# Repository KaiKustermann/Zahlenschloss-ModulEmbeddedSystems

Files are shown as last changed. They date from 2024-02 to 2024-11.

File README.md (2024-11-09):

# Documentation Project Zahlenschloss

## 1. Contributors

- Kai Kustermann (kk147)
- Hannes Frey (hf018)

## 2. Project Description

The project implements a safe using an ATmega328P as microcontroller, a 4x4 matrix keypad to capture user input and an LCD display as output to display important information about the state of the system. Two LEDs are used to indicate if the safe is open or closed. A DC locking bolt acts as mechanic mechanism for closing and opening the lock, which operates using a mosfet. Optionally a buzzer can be added to give auditory feedback to the user.
The project is written in C using AVR-GCC as compiler without any additional libraries as external dependencies.

## 3. Hardware Setup

Hardware needed:
 - Arduino Uno or clone
 - 2 colored LEDs
 - LED resistors
 - 4x4 matrix pin pad
 - 16x2 LCD Display with IO expander
 - Mosfet module
 - 5V bolt pin lock

Depending on how you want to design the safe, you may choose to use our CAD files to directly print oder edit the design to your liking. Alternatively a box made of wood can be crafted based on the original design.

### 3.1 Circuit Diagram

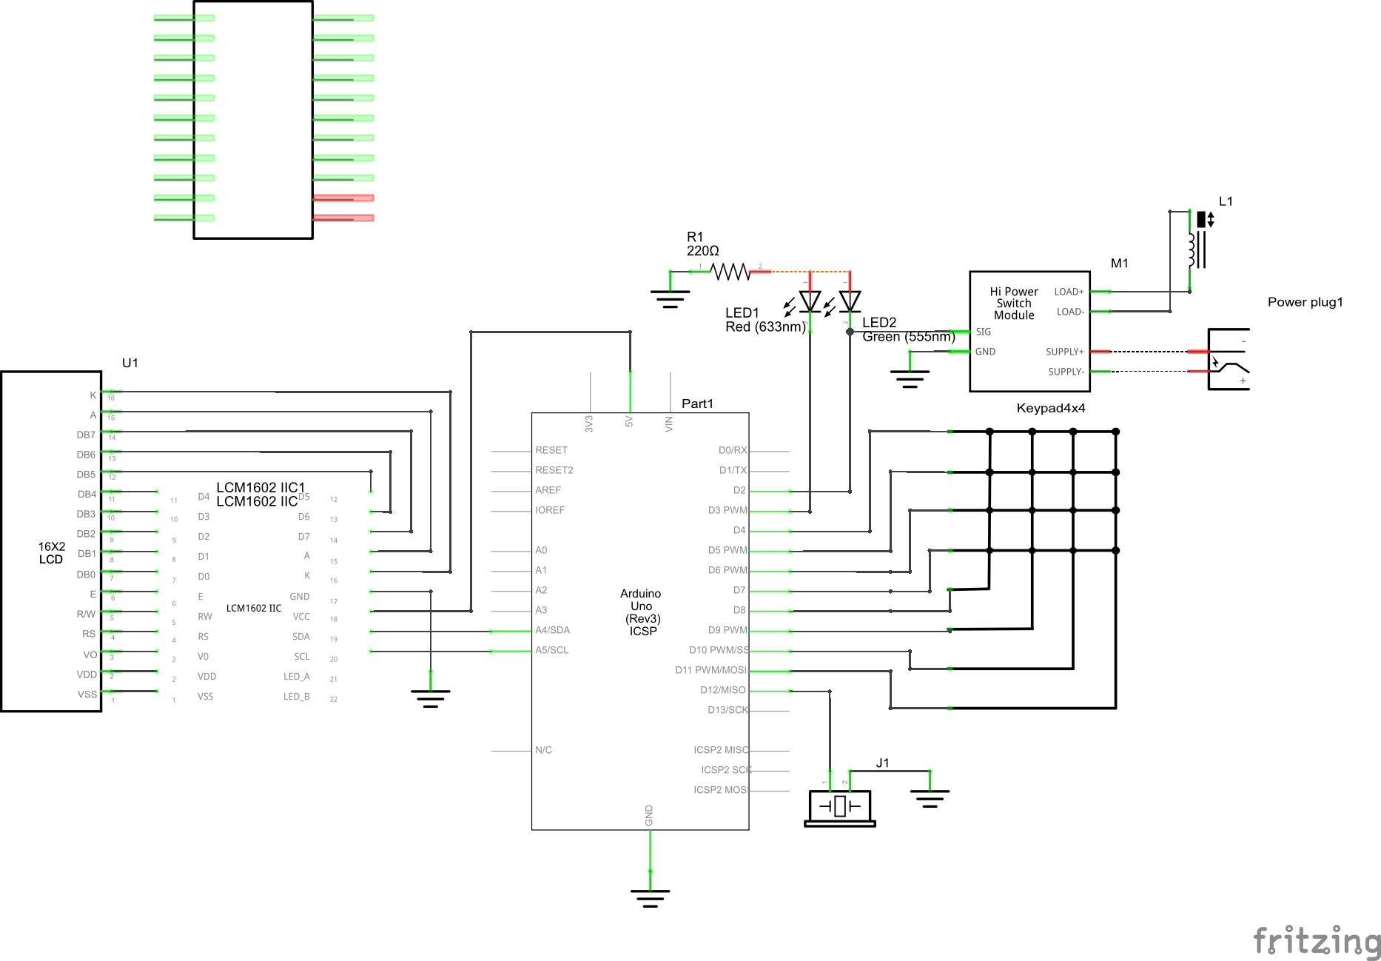
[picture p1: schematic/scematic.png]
Electric schematic


### 3.2 Breadboard Diagram

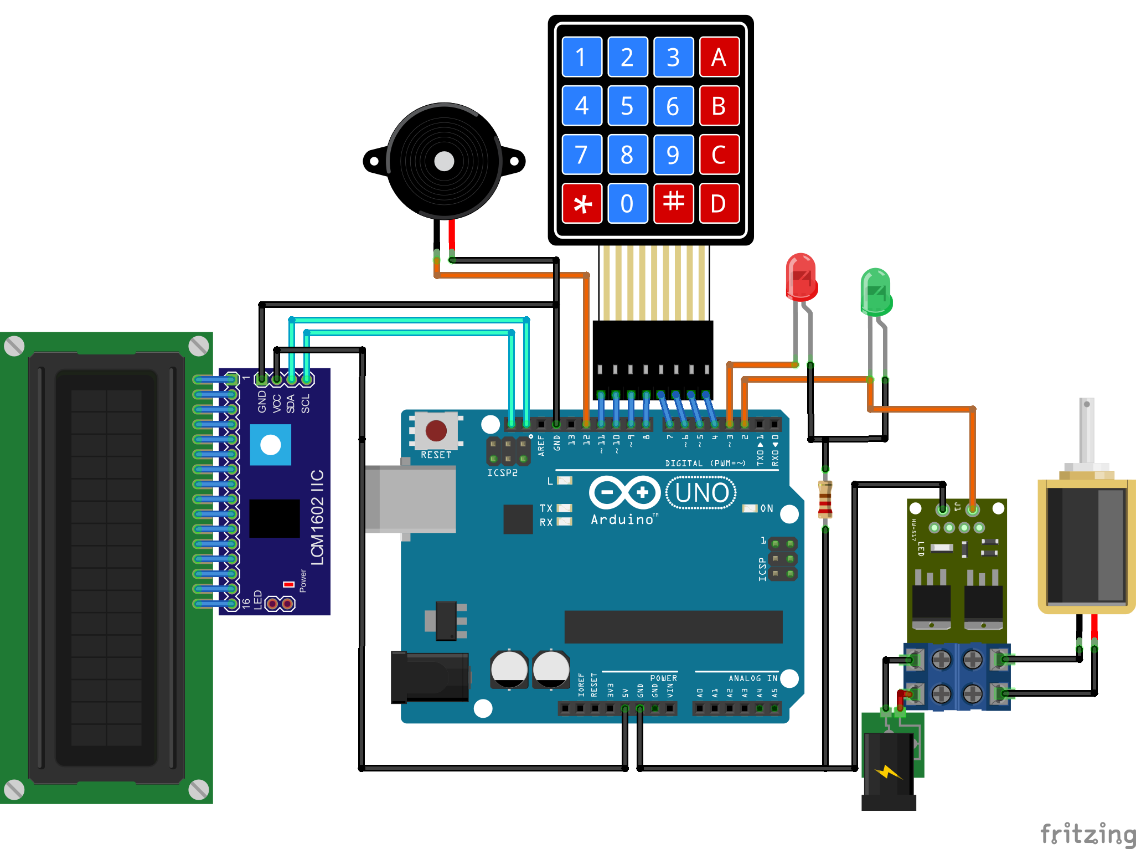
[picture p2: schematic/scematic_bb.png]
Board schematic


### 3.3 Chassis and 3D Printing

Assembled safe with 3D printed chassis           |  Fusion360 Model
:----------------------------------------:|:-------------------------:
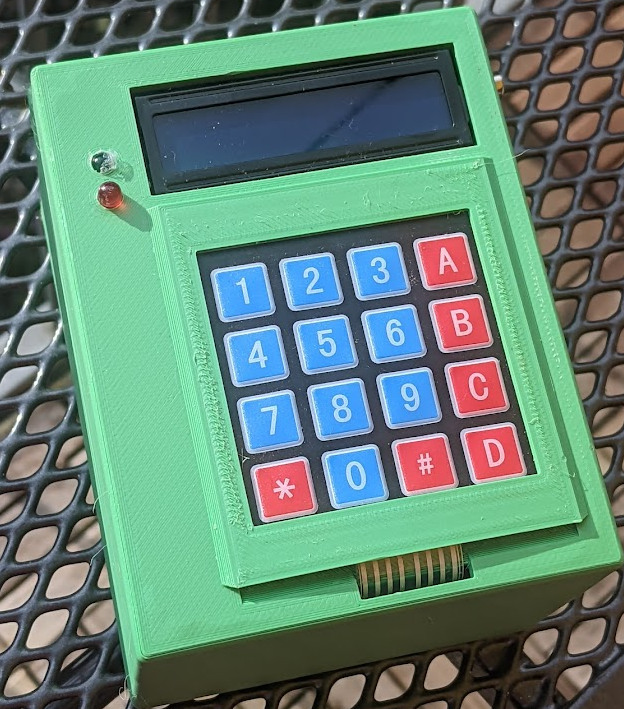
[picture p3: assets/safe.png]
3d printed
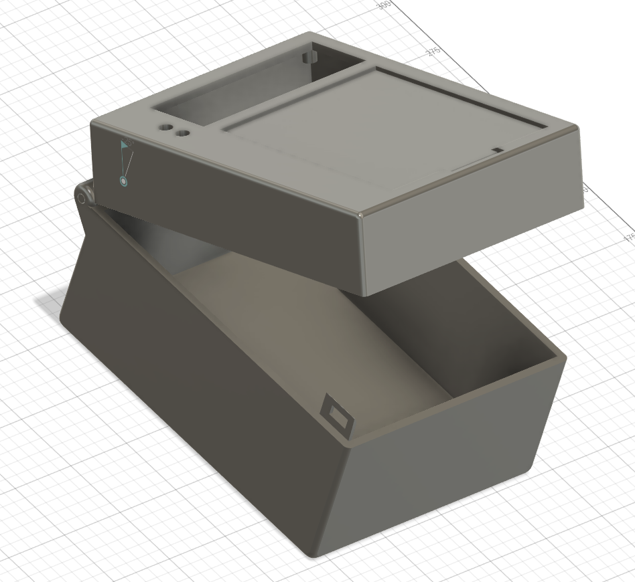
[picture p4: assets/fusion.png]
fusion model
  | 

The fusion file can be found in assets, also stl files for printing the safe directly without modifications. The model has necessary stands for screwing the LCD as well as the Arduino in place.

## 4. Software Setup

The project is exclusively written in C using AVR-GCC as compiler without any additional libraries as external dependencies. For flashing, the software AVRDUDE is used. The tool Make is used for automating the build and deployment process. It is recommended to use VSCode as code editor, as it was used during the development of the project and this documentation contains some useful settings for getting started with development using VSCode.

### 4.1 Download AVR-GCC

Download the AVR-GPP compiler and toolchain for the operating system of your development machine. It is recommended to use the latest version 3.7.0. The official version can be found on the [Microchip website](https://www.microchip.com/en-us/tools-resources/develop/microchip-studio/gcc-compilers).

### 4.2 Download AVRDUDE

Download AVRDUDE for the operating system of your development machine. Please refer to the official [GitHub Repository](https://github.com/avrdudes/avrdude) for detailed installation steps.

### 4.3 Download Make

For the build and deployment process, the tool Make is used. Download Make for the operating system of your development machine.

- Windows:  
  - Download make from [this website](https://gnuwin32.sourceforge.net/packages/make.htm) and follow the installation process
  - Add Make to system PATH environment variable
- Linux:
    `
    sudo apt install make
    `

### 4.4 Logging Setup

For logging messages on the development machine, a USB serial connection from the ATmega328P to the development machine is used. On Windows, we recommend using PuTTY for opening a terminal to the serial port. On Linux the screen command can be used.

- Windows:  
  - Download PuTTY from [the official website](https://putty.org/) and follow the installation process
  - Configure the serial line as follows:
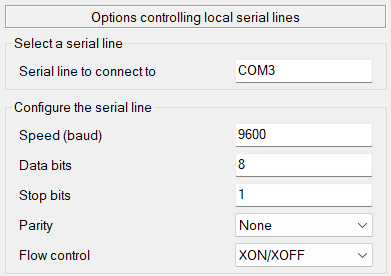
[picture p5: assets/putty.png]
PuTTY settings
    
  - **Important:**
    If you want to change the COM port to a port of your choice, make sure to also change the variable `PROGRAMMER_PORT` in the Makefile.
- Linux:
Use the `screen` command to receive serial data. The syntax is as follows:
`screen [DEVICE NAME] [BAUDRATE]`,  
where the defined baudrate for the atmega328 is 9600.

### 4.5 VSCode Setup (Optional)

VSCode can give a nice development experience by providing helpful features like IntelliSense. Here is an example `c_cpp_properties.json` for configuring the editor on windows.

```json
{
    "configurations": [
        {
            "name": "win32",
            "includePath": [
                "${workspaceFolder}/**",
                "C:\\path\\to\\your\\avr\\download\\avr",
            ],
            "defines": [
                "__AVR_ATmega328P__",
                "F_CPU=16000000UL"
            ],
            "macFrameworkPath": [],
            "compilerPath": "C:\\path\\to\\your\\avr\\download\\bin\\avr-gcc -xc -E -v -",
            "cStandard": "c11",
            "cppStandard": "gnu++14",
            "intelliSenseMode": "clang-x64"
        }
    ],
    "version": 4
}
```

## 5. Build and Deployment

First, configure the program to your needs in main.c. An important setting is the environment setting (DEV or PROD), which disables logging in PROD for performance gains.
The build and deployment process is automated with a Makefile. It provides the following commands:  

- To flash the project onto an ATmega328P microcontroller, use the command:
`make program`  
For Windows, the default programmer port is set to COM3, for Linux it is set to /dev/ttyUSB0. Make sure to connect the ATmega328P to the right USB port or change the setting.
- To remove the generated .hex, .elf and .o files from your development machine, use the command:
`make clean`  

### Makefile

The build step, which is defined in the Makefile uses the AVR-GCC compiler to compile and link the project. It automatically converts all C and C++ files to object files and then transforms them into linked .elf files. After that, the command `avr-objcopy` is used to create .hex files, which contain machine language code in hexidecimal form. AVRDUDE is used to write the .hex file to the flash memory of the microcontroller.

## 6. Code

The code is structured like follows:

```bash
├── main.c
├── configuration.h
├── drivers
│  ├── buzzer.c
│   ├── buzzer.h
│   ├── i2c.c
│   ├── i2c.h
│   ├── keypad.c
│   ├── keypad.h
│   ├── lcd.c
│   └── lcd.h
├── helpers
│   ├── eepromHelpers.c
│   ├── eepromHelpers.h
│   ├── stringHelpers.c
│   ├── stringHelpers.h
│   ├── timerHelpers.c
│   └── timerHelpers.h
├── lock
│   ├── hashing.c
│   ├── hashing.h
│   ├── lock.c
│   ├── lock.h
│   ├── program.c
│   └── program.h
├── logging
    ├── logging.c
    ├── logging.h
    ├── uart.c
    └── uart.h
```

The main logic of the program can be found lock.c in the lock folder, including the state machine of the lock. Several helpers, as well as drivers are used in the application, of which keypad.c and lcd.c are the most important ones, as they represent the drivers for the I/O hardware.
The lock can be configured in main.c.
For more information about the code and specific functions, please refer to the code comments.

## 7. Operation Manual

The safe is controlled via keypad and gives feedback on an LCD display. The safe can be in 5 different states with different behaviors and functions.

### Keypad

The core keypad functions are the same in each state. The keypad has 10 blue number keys, which can be used for the pin code and 6 red symbol keys, which have different functions:

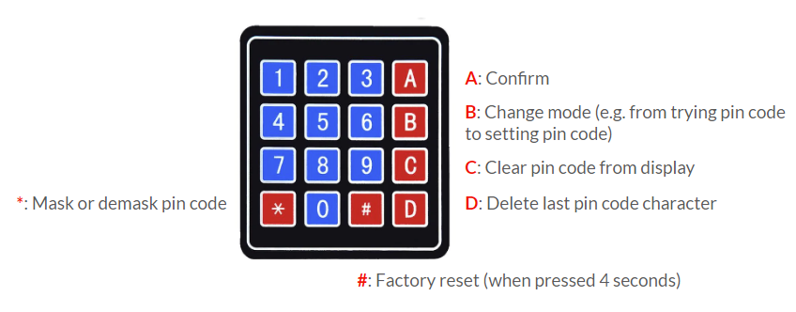
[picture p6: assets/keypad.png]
Keypad


### Display

The display gives feedback regarding the state of the system as well as the given pin code and additional temporary help messages.

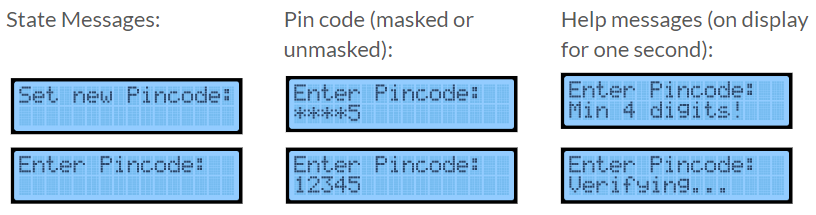
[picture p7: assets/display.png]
Display


### States

1. **Setting the initial pin code**:
When first turning on the safe, you will be prompted to set a new pin code.
2. **Entering the pin code**: When a pin code is set, you are prompted to enter the currently set pin code to open the lock. When pressing B in this state, the safe will enter state 4.
3. **Opening the lock**: When the right pin code was entered, the lock opens. When pressing B in this state, the safe will enter state 2.
4. **Setting a new pin code**: This state asks for the set pin code first. If the given pin code is right, it will let you set a new pin code. When pressing B in this state, the safe will enter state 2.
5. **Resetting to factory settings**: When holding the key # in any state for 4 seconds, the safe will enter the reset state. Here, you are prompted to enter the currently set pin code. If the correct pin code is entered, the lock will reset itself to factory settings.

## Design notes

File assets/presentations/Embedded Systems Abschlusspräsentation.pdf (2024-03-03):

# Embedded Systems Abschlusspräsentation

### Hannes Frey und Kai Kustermann

# Agenda

### - Die ursprüngliche Vision

### - Hardwarearchitektur

### - Implementierte Features

### - Demo

### - Zeitplanung (Meilensteine)

### - Kostenplanung

### - Lessons Learned

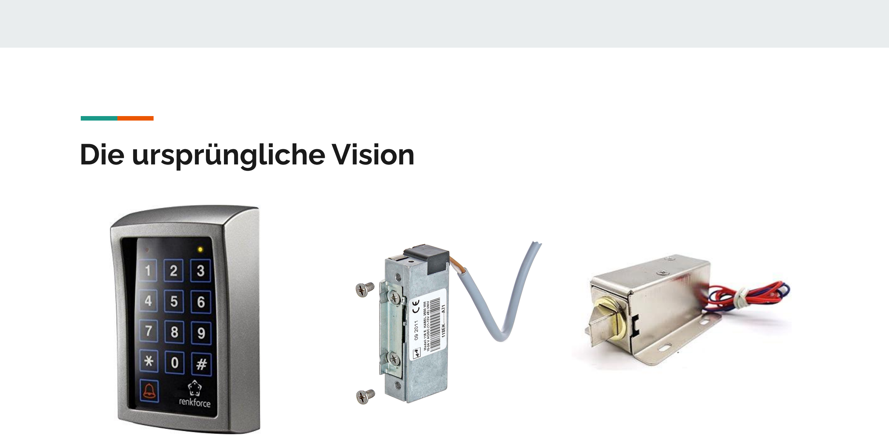
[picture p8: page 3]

# Die ursprüngliche Vision

# Hardwarearchitektur

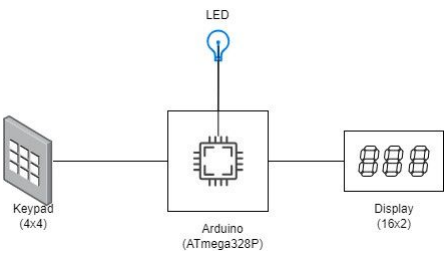
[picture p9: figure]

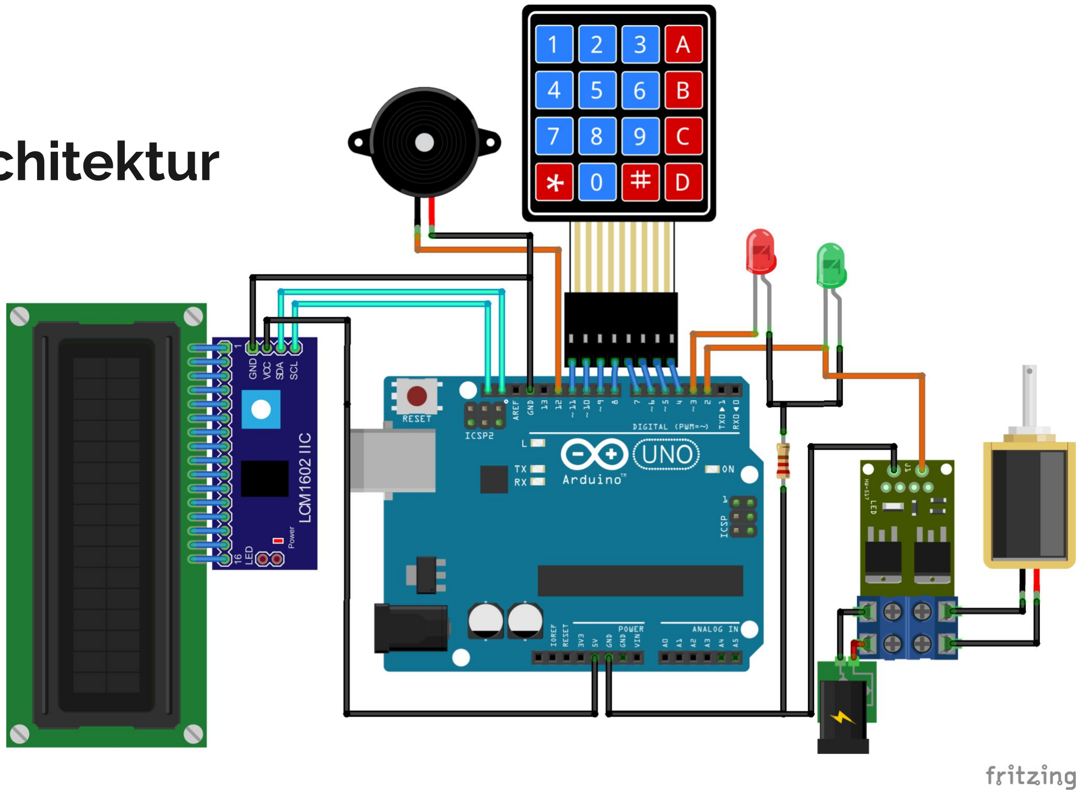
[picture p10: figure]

# Hardwarearchitektur

# Implementierte Features

### Treiber:

- I2C
- LCD Display
- Keypad
- EEPROM (Electrically Erasable Programmable Read Only Memory)
- USART (Universal Synchrones Serielles Interface)
- Buzzer

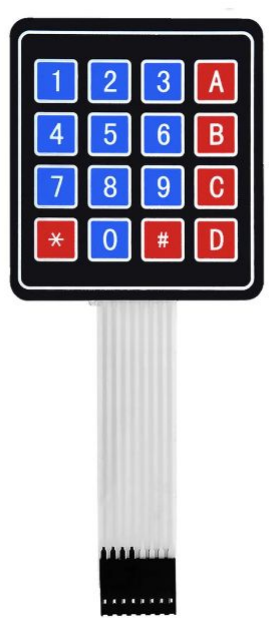
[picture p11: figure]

# Implementierte Features

### Zahlenschloss:

- Keypad:
- 10 Tasten,
welche für den Pin verwendet werden können
- 6 Tasten,
welche andere Funktionen besitzen

# Implementierte Features

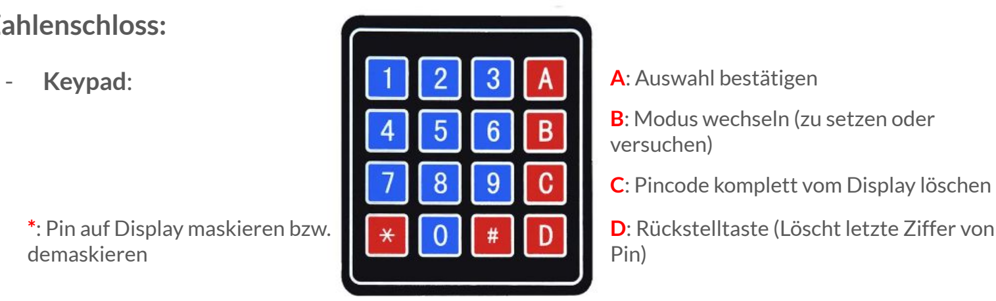
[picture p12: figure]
Keypad:; A: Auswahl bestätigen; B: Modus wechseln (zu setzen oder versuchen); C: Pincode komplett vom Display löschen

### Zahlenschloss:

D: Rückstelltaste (Löscht letzte Ziffer von Pin)

*: Pin auf Display maskieren bzw. demaskieren

#: Zahlenschloss auf Werkseinstellungen zurücksetzen (wenn über 4 Sekunden gedrückt)

# Implementierte Features

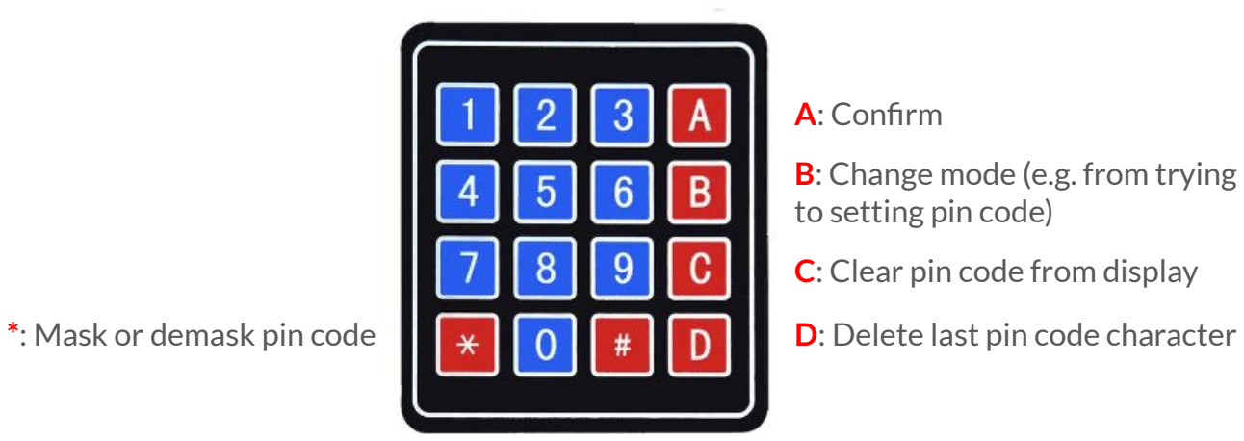
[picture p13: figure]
A: Confirm; to setting pin code); C: Clear pin code from display; *: Mask or demask pin code; D: Delete last pin code character

B: Change mode (e.g. from trying pin code

#: Factory reset (when pressed 4 seconds)

# Implementierte Features

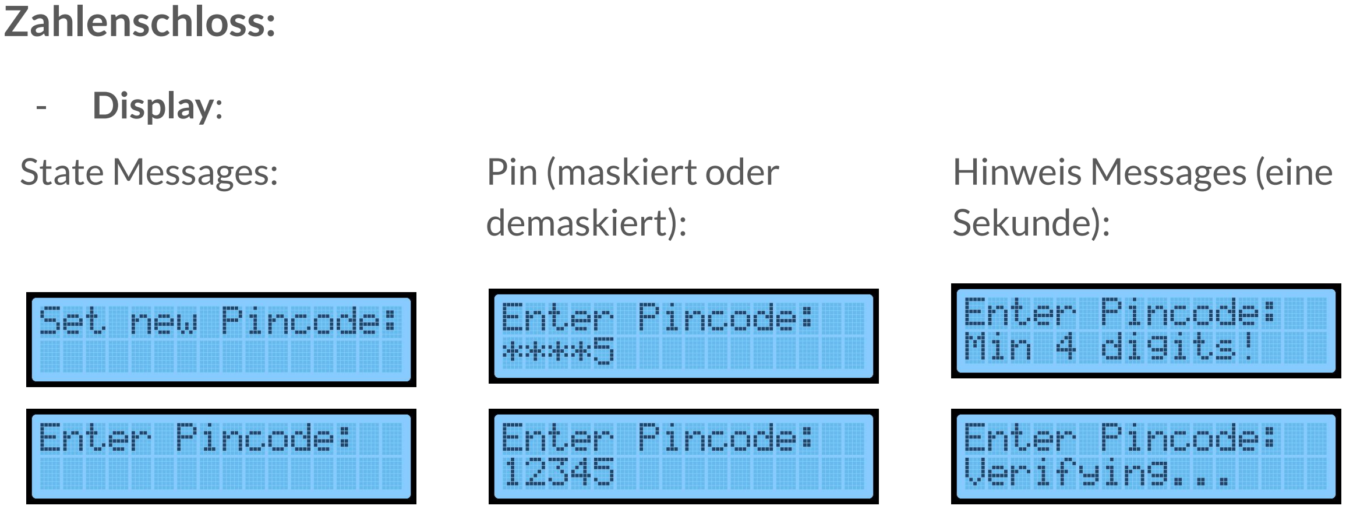
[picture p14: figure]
State Messages:; Pin (maskiert oder; demaskiert):; Hinweis Messages (eine Sekunde):; Zahlenschloss:; - Display:

State Messages: | Pin code (masked or unmasked):

Help messages (on display
for one second):

# Implementierte Features

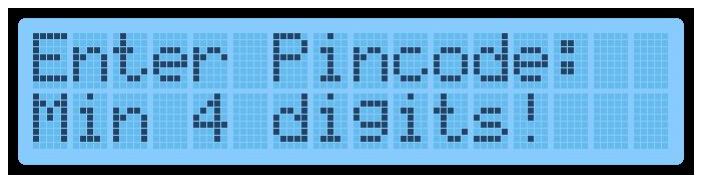
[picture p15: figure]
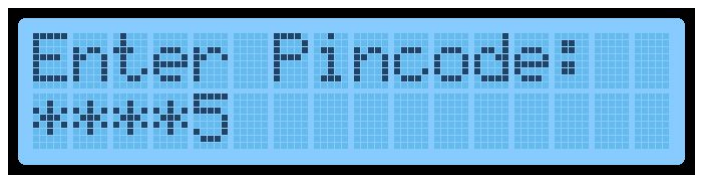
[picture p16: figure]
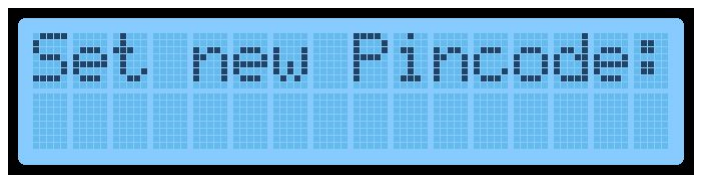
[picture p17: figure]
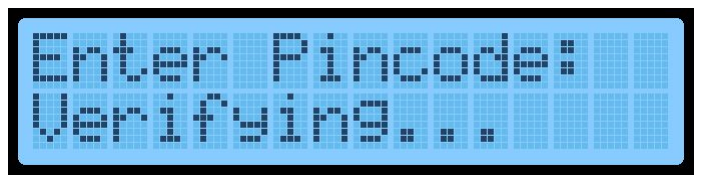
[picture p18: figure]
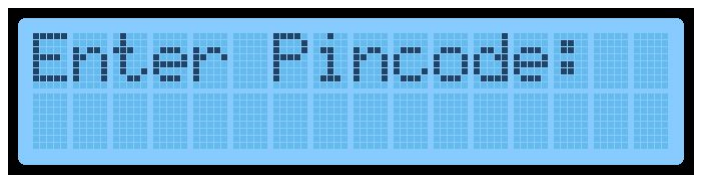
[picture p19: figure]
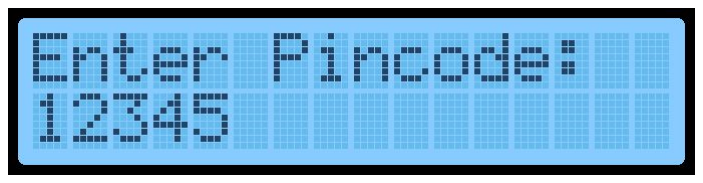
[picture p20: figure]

# Implementierte Features

### Zahlenschloss:

- 5 verschiedene Hauptfunktionen (User Stories):
- Setzen des initialen Pincodes
- Eingabe des Pincodes
- Öffnen des Schlosses -> LED geht an und Schloss wird geöffnet
- Setzen eines neuen Pincodes
- Reset auf Werkseinstellungen

# Implementierte Features

### Zahlenschloss:

- User Story: Setzen des initialen Pincodes

# DEMO

# Implementierte Features

### Zahlenschloss:

- User Story: Eingabe des Pincodes

# DEMO

# Implementierte Features

### Security:

### - Hashing mit DJB2 und zufällig generiertem Salt - Zeitunabhängige Vergleichsfunktion fürs strings => Länge des gespeicherten Pins bleibt verborgen

# Zeitplanung (Meilensteine)

Milestone 1:
Setup, Display, Keypad

20.12.2023

Milestone 2:
Logik für Keypad,
Display und Schloss

20.01.2024 Milestone 3:

LED, Lautsprecher,
Bolzenschloss

30.01.2024

# Kostenanalyse

Produkt | Preis
3x AZ-ATmega328DIP | 19,99 €
3x AZ-Delivery HD44780 1602 LCD module Display | 12,99 €
3x AZ-Delivery 4x4 Matrix Array Keypad | 6,99 €
Kleinstmaterial (Lötzinn, Kabel, Widerstände, …) | max 10 €
3D-Druck | 5 €
Netzteil, Mosfet-Modul, DC-Bolzen, DC Plug | 26 €

# Lessons Learned

## - HdM Weihnachtspause - Hardware Entwicklung/Debugging -> an Hardware arbeiten

- Löten etc.

## - Gitlab Issues/MR Workflow - Hat Spaß gemacht

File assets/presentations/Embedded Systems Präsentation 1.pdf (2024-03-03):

# Embedded Systems Projektvorstellung

Hannes Frey und Kai Kustermann

# Agenda

### - Die Idee

### - Architektur und Umsetzung

### - Risikoanalyse

### - Zeitplanung

### - Kostenplanung

### - Verantwortlichkeiten innerhalb des Teams

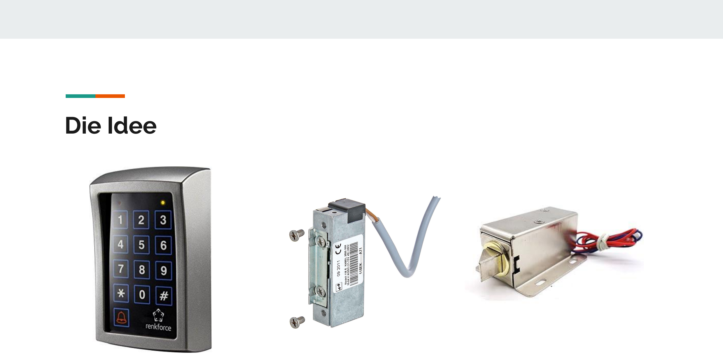
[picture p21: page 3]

# Die Idee

# Architektur


# Bauteile - Mikrocontroller

## - AZ-ATmega328DIP Board

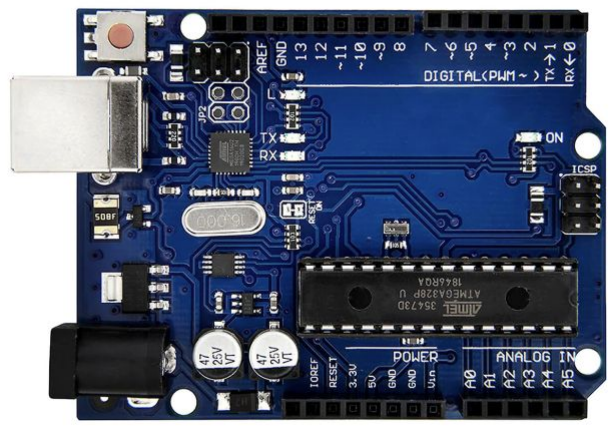
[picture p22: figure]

## - Mit ATmega328p Mikrocontroller

# Bauteile - Display

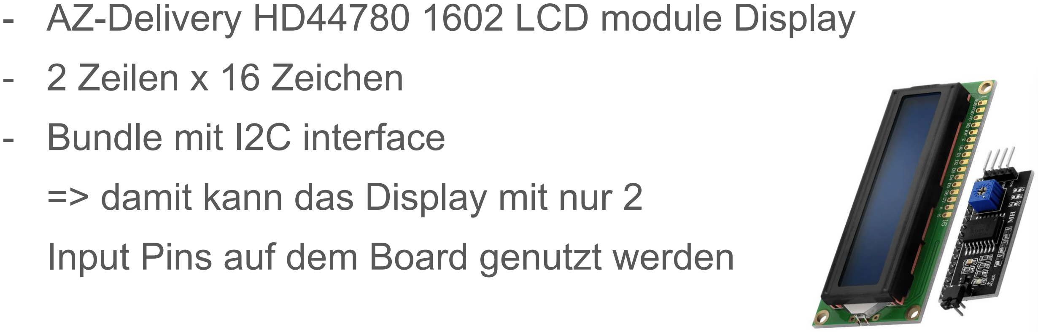
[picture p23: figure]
- 2 Zeilen x 16 Zeichen; - Bundle mit I2C interface; => damit kann das Display mit nur 2; Input Pins auf dem Board genutzt werden

## - AZ-Delivery HD44780 1602 LCD module Display

# Bauteile - Tastenfeld


## - AZ-Delivery 4x4 Matrix Array Keypad

## - 16 Tasten

## - 8 Kabel => 8 Pins auf Board

# Risikoanalyse

Ereignis | Eintrittswahrs cheinlichkeit | Schwere | Priorität | Maßnahmen
nicht möglich LCD Protokoll, Ansteuern | mittel | mittel | hoch | Priorisiert Ressourcen in LCD stecken
Löten schlägt fehl, beschädigt Bauteile | mittel | niedrig | mittel | Vor wichtigen Lötpunkten üben, im Notfall auch über Breadboard funktionabel
Hardware geht/ist kaputt | niedrig | hoch | niedrig | Vorsorglich ein Board mehr besorgen

# Meilensteine

Meilenstein 1 (20.12.):

- Setup
- Tastenfeld mit Mikrocontroller verbinden
- Logik zum Auslesen der Tastendrücke
- Display mit Mikrocontroller verbinden

Meilenstein 2 (20.01):

- Logik zur Darstellung von Zeichen auf Display
- Logik für Zahlenschloss (Speichern von Kombinationen, Öffnen bei Eingabe der richtigen Kombination, Speichern von Passwortrichtlinien usw.)

# Meilensteine

Meilenstein 3 (30.01.):

- Einbinden Speaker oder Riegel/Pin für Öffnung des Schlosses (optional)
- Testing und Bugfixing

# Kosten

Produkt | Preis
3x AZ-ATmega328DIP | 19,99 €
3x AZ-Delivery HD44780 1602 LCD module Display | 12,99 €
3x AZ-Delivery 4x4 Matrix Array Keypad | 6,99 €
Kleinstmaterial (Lötzinn, Kabel, Widerstände, …) | max 10 €

# Verantwortlichkeiten

## - Kai: - Projektmanagement - Programmierung (Tastenfeld, Logik Zahlenschloss) - Hannes: - Hardwarenahe Themen (Löten usw.) - Programmierung (Display, Logik Zahlenschloss)

# Quellen

- https://www.az-delivery.de/

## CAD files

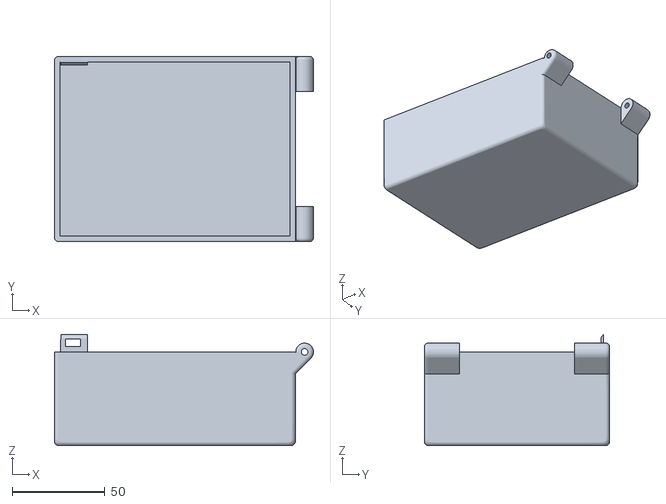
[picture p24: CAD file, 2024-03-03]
assets/model/Bottom.stl
139.8 x 100.0 x 60.1

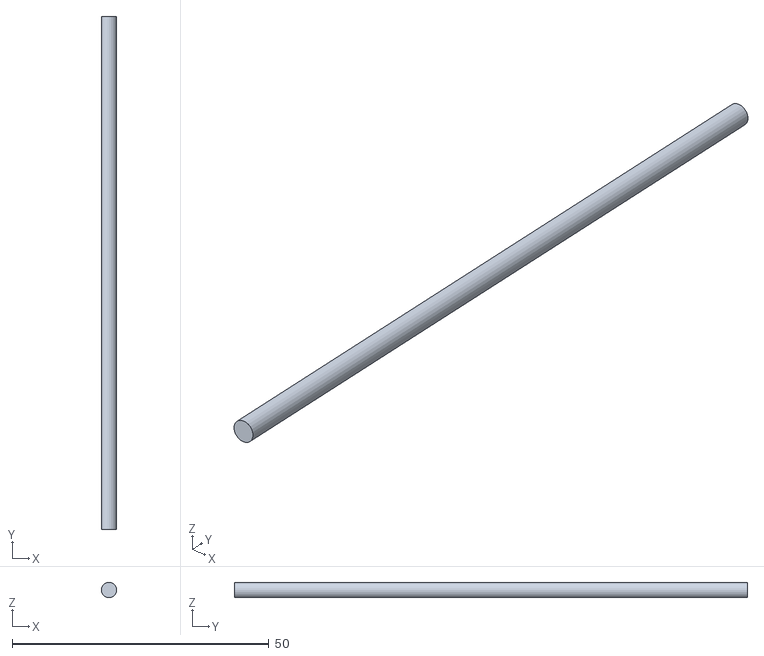
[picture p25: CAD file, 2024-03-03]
assets/model/Pin.stl
3.00 x 100.0 x 3.00

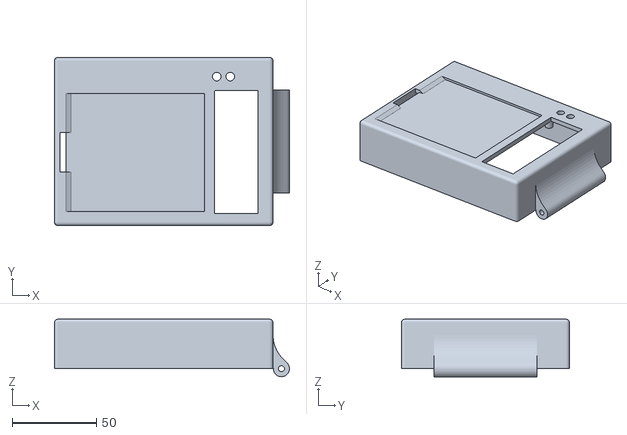
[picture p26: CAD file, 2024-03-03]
assets/model/Top.stl
139.8 x 100.0 x 34.2

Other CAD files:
assets/model/Tresor.f3d

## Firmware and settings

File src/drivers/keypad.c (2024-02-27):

#include <avr/io.h>
#include <util/delay.h>
#include <avr/interrupt.h>
#include <stdio.h>

#include "keypad.h"
#include "../helpers/timerHelpers.h"

#define DDR_KEYPAD_ROWS DDRD
#define DDR_KEYPAD_COLS DDRB
#define PORT_KEYPAD_ROWS PORTD
#define PORT_KEYPAD_COLS PORTB
#define PIN_KEYPAD_ROWS PIND
#define PIN_KEYPAD_COLS PINB
#define PCIE_KEYPAD PCIE0
#define PCMSK_KEYPAD PCMSK0
#define PCINT_KEYPAD PCINT0_vect
// mapping to pins of ports (e.g. ROW_0 is pin 4 on PORT_KEYPAD_ROWS)
#define ROW_0 4
#define ROW_1 5
#define ROW_2 6
#define ROW_3 7
#define COL_0 0
#define COL_1 1
#define COL_2 2
#define COL_3 3

// keypad layout
uint8_t keypad[4][4] = {{'1','2','3','A'},
                        {'4','5','6','B'},
                        {'7','8','9','C'},
                        {'*','0','#','D'}};

uint8_t keyChanged = 0; //flag that is a non zero value if a key has changed and 0 if it has not

// 0 when no key pressed
uint8_t currentPressedKey = 0;

on_key_changed_function_t* keyPressHandler;

// initializes the keypad
void keypadInit(){
    // set rows as output (set to 1) using the data direction registry
    DDR_KEYPAD_ROWS |= (1 << ROW_0) | (1 << ROW_1) | (1 << ROW_2) | (1 << ROW_3);
    // set columns as input (set to 0) using the data direction registry; detailed: 00000001 | 00000010 | 00000100| 00001000 -> 00001111 -> 11110000 -> with bitwise and the pins with 1 stay 1 (e.g. before: DDR_KEYPAD = 10101010; mask: 11110000; result: 10100000)
    DDR_KEYPAD_COLS &= ~((1 << COL_0) | (1 << COL_1) | (1 << COL_2) | (1 << COL_3));
    // set internal pullup for columns (set to 1) by setting the right ports to 1
    PORT_KEYPAD_COLS |= (1 << COL_0) | (1 << COL_1) | (1 << COL_2) | (1 << COL_3);
    // set rows as low (set to 0) by setting the right ports to 0 
    PORT_KEYPAD_ROWS  &= ~((1 << ROW_0) | (1 << ROW_1) | (1 << ROW_2) | (1 << ROW_3));
    // enable pin change interrupt for port of keypad
    PCICR |= (1 << PCIE_KEYPAD);
    // control which pins you want to get the interrupt from (all columns)
    PCMSK_KEYPAD |= (1 << COL_0) | (1 << COL_1) | (1 << COL_2) | (1 << COL_3);
}   

/* 
finds the pressed key using column scanning technique (columns as input to the microcontroller)
detailed: going through the rows (outputs to microcontroller) and applying ground (0) to each row. 
then reading the columns (inputs to microcontroller), which are pulled up (1) by default. 
if a column is 0, the key in this row for this column was pressed, 
because there flows a current from the row output pin to the column input pin.
*/ 
uint8_t findPressedKey(){
    // disable pin change interrupt for column pins
    PCMSK_KEYPAD &= ~((1 << COL_0) | (1 << COL_1) | (1 << COL_2) | (1 << COL_3));
    const uint8_t rows[4] = {ROW_0, ROW_1, ROW_2, ROW_3};
    const uint8_t cols[4] = {COL_0, COL_1, COL_2, COL_3};
    for (uint8_t row=0; row<4; row++){
        // set all rows high (1)
        PORT_KEYPAD_ROWS  |= (1 << ROW_0) | (1 << ROW_1) | (1 << ROW_2) | (1 << ROW_3);
        // set current row to low (0)
        PORT_KEYPAD_ROWS &=~(1<<rows[row]);
        for(uint8_t col=0; col<4; col++){
            // check if column is low (0), therefore pressed
            if((PIN_KEYPAD_COLS & (1<<cols[col])) == 0){
                // set rows as low (set to 0) by setting the right ports to 0 
                PORT_KEYPAD_ROWS  &= ~((1 << ROW_0) | (1 << ROW_1) | (1 << ROW_2) | (1 << ROW_3));
                // enable pin change interrupt for pins
                PCMSK_KEYPAD |= (1 << COL_0) | (1 << COL_1) | (1 << COL_2) | (1 << COL_3);
                return keypad[row][col];
            }
        }
    }
    // set rows as low (set to 0) by setting the right ports to 0 
    PORT_KEYPAD_ROWS  &= ~((1 << ROW_0) | (1 << ROW_1) | (1 << ROW_2) | (1 << ROW_3));
    // enable pin change interrupt for pins
    PCMSK_KEYPAD |= (1 << COL_0) | (1 << COL_1) | (1 << COL_2) | (1 << COL_3);
    return 0;
}

// returns a non zero value if the key has been changed (pressed or released)
uint8_t hasKeyChanged(){
    return keyChanged;
}

// sets the given function as handler for a key press
void setKeyPressHandler(on_key_changed_function_t* keyPressHandlerFunction){
    keyPressHandler = keyPressHandlerFunction;
}

// calls the key event handler function
void sendKeyEvent(keyEventType eventType) {
    struct keyEvent keyPressEvent;
    keyPressEvent.pressEventType = eventType;
    keyPressEvent.pressedKey = (unsigned char)currentPressedKey;
    keyPressEvent.pressDuration = getMillis();
    keyPressHandler(keyPressEvent);
}

// runs the keypad and calls the key event handler function in case of a key event
void keypadRun(){
    // check if the key state has changed (flag has been set by interrupt)
    if (hasKeyChanged() != 0) {
        uint8_t pressedKey = findPressedKey();
        // handle key press
        if (pressedKey != 0) {
            initTimer();
            currentPressedKey = pressedKey;
            sendKeyEvent(KEY_PRESS_START);
        } 
        // handle key release
        else {
            sendKeyEvent(KEY_PRESS_END);
            currentPressedKey = 0;
            resetTimer();
        }
        // reset keyChanged variable
        keyChanged = 0;
    } 
    // handle key hold
    else if (currentPressedKey != 0) {
        sendKeyEvent(KEY_HOLD);
    } 
    // handle no key pressed
    else {
        sendKeyEvent(KEY_NONE);
    }
}

// interrupt service routine for pins of columns
ISR(PCINT_KEYPAD){
    keyChanged = 1;
}

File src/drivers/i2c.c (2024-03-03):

#include <avr/io.h>

#include "i2c.h"

void I2CInit(void)
{
	/* SCL CLOCK
	 * CPU 16Mhz CLK 100khz
	 */
	TWBR = 0x48; // Set the TWI Bit Rate Register to achieve a 100kHz SCL clock
}

void I2CStart(void)
{
	TWCR = (1 << TWINT) | (1 << TWSTA) | (1 << TWEN); // Send START condition on TWI bus
	while (!(TWCR & (1 << TWINT))) // Wait until START condition is transmitted
		;
}

void I2CSend(unsigned char data)
{
	TWDR = data; // Load data into TWI Data Register
	TWCR = (1 << TWINT) | (1 << TWEN); // Start transmission of data
	while (!(TWCR & (1 << TWINT))) // Wait until data is transmitted
		;
}

void I2CSendByAddr(unsigned char data, unsigned char addr)
{
	I2CStart(); // Send START condition
	I2CSend(addr); // Send address byte
	I2CSend(data); // Send data byte
	I2CStop(); // Send STOP condition
}

void I2CStop(void)
{
	TWCR = (1 << TWINT) | (1 << TWSTO) | (1 << TWEN); // Send STOP condition on TWI bus
}

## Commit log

2023-12-12 added other algorithm for keypad driver
2023-12-15 keypad interrupt routine added
2023-12-17 improved interrupt service handler (using flag to escape fast)
2023-12-17 removed lock logic from arduino.c for this MR
2023-12-22 LED lights up an opening of lock, cleanup arduino.c
2024-01-17 keypad button released logic added
2024-01-17 millis added
2024-01-17 improved timer for key press duration in timerHelpers and keypad.c, removed function arguments in lock.c because global variables are used instead
2024-01-22 i2c and lcd driver
2024-01-25 add LED logic, LED should be connected to pin 2
2024-01-27 added logging based on environment
    [configuration.h]
2024-01-27 fix led
2024-01-28 add fitzing schematic and exports
    [scematic.fzz]
2024-02-13 folder structure introduced
    [configuration.h]
2024-03-03 extend readme, add inline comments
    [Bottom.stl, Pin.stl, Top.stl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]
